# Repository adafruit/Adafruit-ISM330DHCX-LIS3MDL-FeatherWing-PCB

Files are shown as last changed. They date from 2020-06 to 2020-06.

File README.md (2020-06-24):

## Adafruit ISM330DHCX + LIS3MDL FeatherWing - High Precision 9-DoF IMU PCB

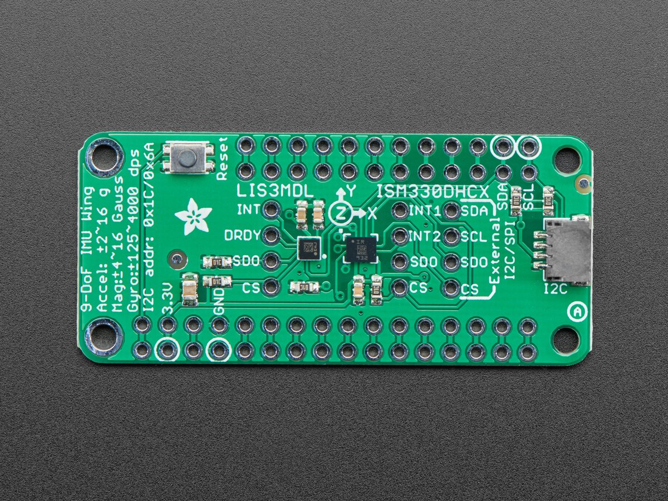
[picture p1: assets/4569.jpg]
<a href="http://www.adafruit.com/products/4569"><br/>
Click here to purchase one from the Adafruit shop</a>

PCB files for the Adafruit ISM330DHCX + LIS3MDL FeatherWing - High Precision 9-DoF IMU.

Format is EagleCAD schematic and board layout
* https://www.adafruit.com/product/4569

### Description

Upgrade any Feather board with precision motion sensing with the ST 9-DoF IMU, an all-in-one sensing 'Wing. It sports two fantastic sensors from ST to provide 9 degrees of full-motion data.

The ST ISM330DHCX is an industrial quality Accelerometer+Gyroscope 6-DOF IMUs (inertial measurement unit). This IMU sensor has 6 degrees of freedom - 3 degrees each of linear acceleration and angular velocity at varying rates within a respectable range. For the accelerometer: ±2/±4/±8/±16 g at 1.6 Hz to 6.7KHz update rate. For the gyroscope: ±125/±250/±500/±1000/±2000/±4000 dps at 12.5 Hz to 6.7 KHz. In particular, this is one of the few gyro's we stock with 4000 dps range, usually they top out at 2000. This sensor has extra calibration and compensation circuits to give it excellent performance in a wide environmental range from -40 to +105°C. Most other IMU sensors don't have industrial temperature ranges or have wide accuracy variation as the temperature changes. The accelerometer and gyroscope also are on the same silicon die, which will keep the 6 measurements synchronized better than when the two sensors are on separate dies.

There are also some nice extras, such as built-in tap detection, activity detection, pedometer/step counter and a programmable finite state machine / machine learning core that can perform some basic gesture recognition.

It also includes a LIS3MDL 3-axis magnetometer that can sense where the strongest magnetic force is coming from, generally used to detect magnetic north. The three triple-axis sensors add up to 9 degrees of freedom, by combining this data you can orient the board. Check out our guide on how to do that!

Both sensors are connected over the shared I2C bus, so you can use it with any and all Feathers! We also break out the interrupt pins and address-selection jumpers in case you want multiple Feathers or have I2C address conflicts. We've got both Arduino (C/C++) and CircuitPython libraries available so you can use it with any Feather board and get data readings in under 5 minutes. Four mounting holes make for a secure connection.

Additionally, since it speaks I2C you can easily connect it up with two wires (plus power and ground!).  We've even included SparkFun qwiic compatible STEMMA QT connectors for the I2C bus so you don't even need to solder! Just wire up to your favorite micro like the STM32F405 Feather with a plug-and-play cable to get 9 DoF data ASAP. You can change the I2C addresses on the back using the solder jumpers, to have two of these sensor boards on one bus.

We also wrote libraries to help you get these sensors integrated with your Arduino/C++. This library covers the accel/gyro and this library is for the magnetometer.

Check out the learning guide here for more information like schematics, wiring diagrams and code libraries.

### License

Adafruit invests time and resources providing this open source design, please support Adafruit and open-source hardware by purchasing products from [Adafruit](https://www.adafruit.com)!

Designed by Limor Fried/Ladyada for Adafruit Industries.

Creative Commons Attribution/Share-Alike, all text above must be included in any redistribution.
See license.txt for additional details.

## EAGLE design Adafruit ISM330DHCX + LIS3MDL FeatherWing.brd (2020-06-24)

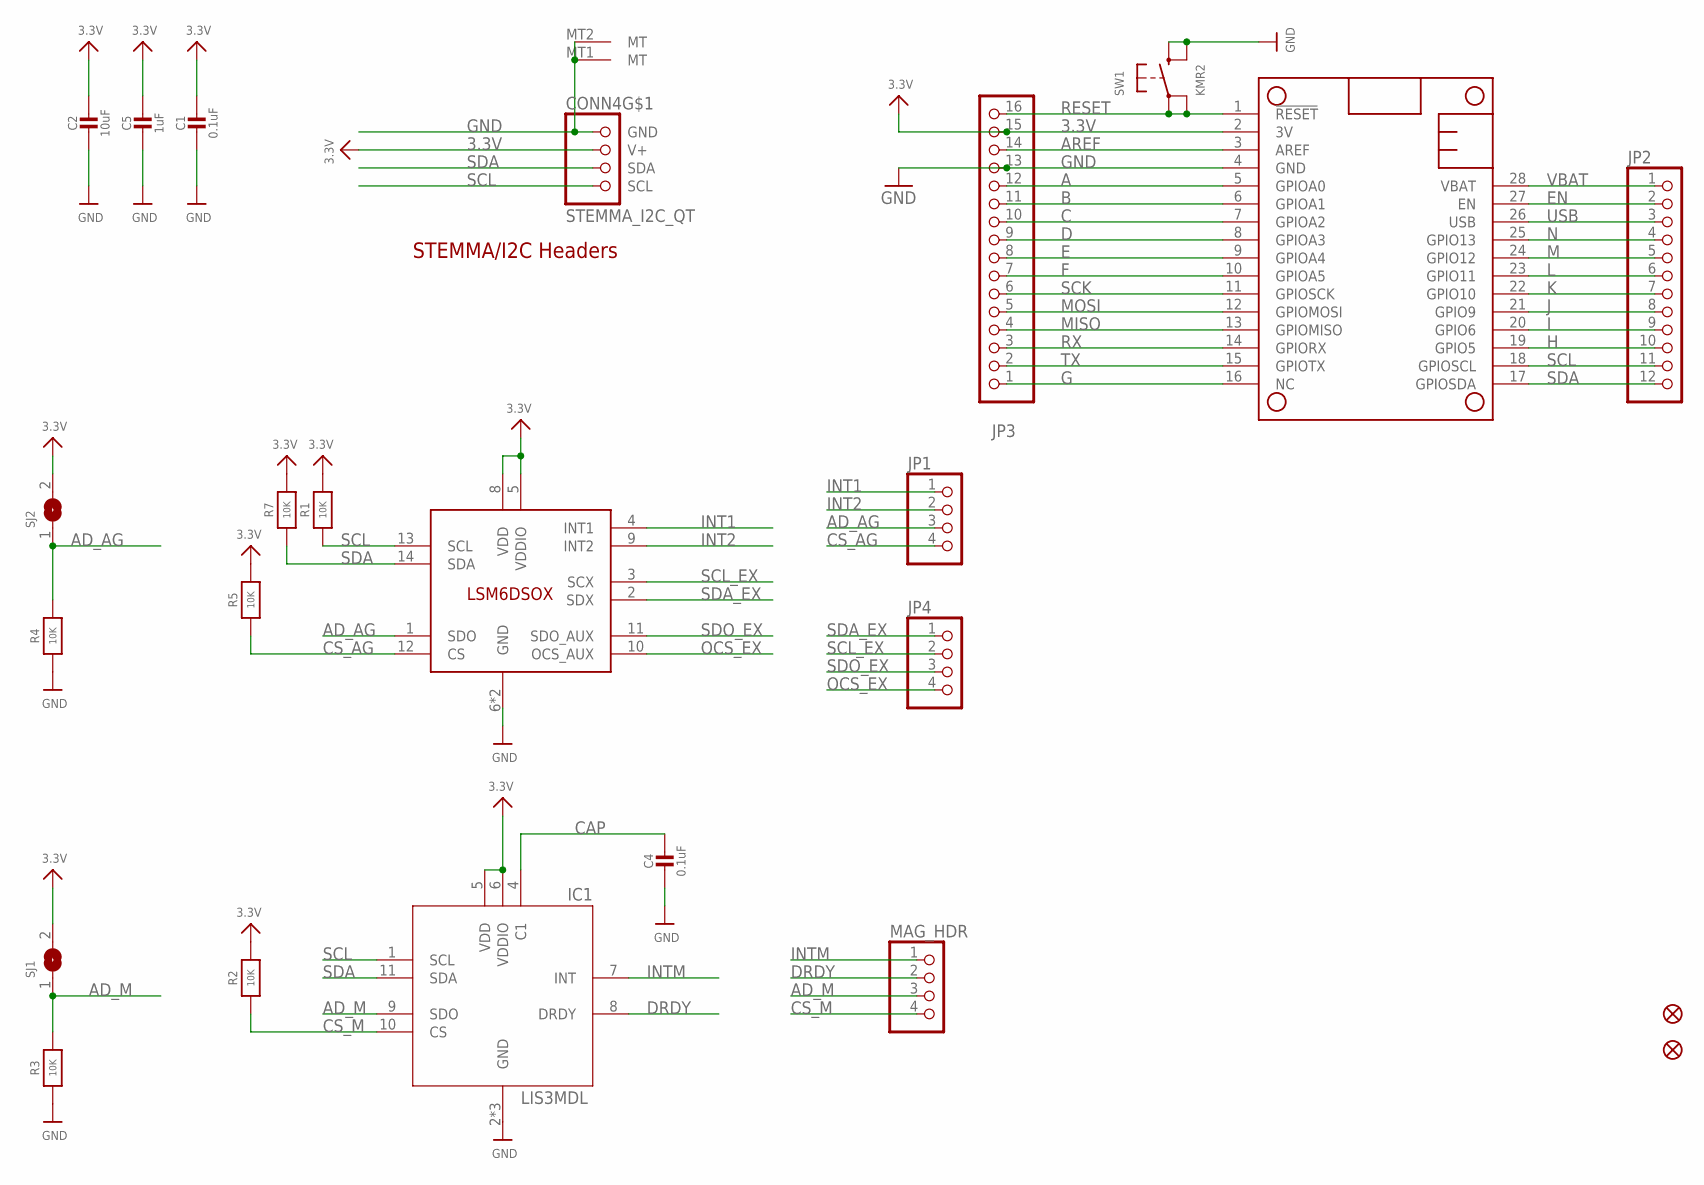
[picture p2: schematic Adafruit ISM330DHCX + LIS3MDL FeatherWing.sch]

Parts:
C1, C4: 0.1uF; 0603-NO
C2: 10uF; 0805-NO
C5: 1uF; 0603-NO
CONN4: STEMMA_I2C_QT; JST_SH4
FID1, FID2: FIDUCIAL_1MM
IC1: LIS3MDL; LGA12_2X2MM
JP1, JP4: HEADER-1X4ROUND; 1X04_ROUND
JP2: HEADER-1X12; 1X12_ROUND
JP3: HEADER-1X16ROUND; 1X16_ROUND
MAG_HDR: HEADER-1X4ROUND; 1X04_ROUND
MS1: FEATHERWING
R1, R2, R3, R4, R5, R7: 10K; 0603-NO
SJ1, SJ2: SOLDERJUMPER; SOLDERJUMPER_ARROW_NOPASTE
SW1: KMR2; BTN_KMR2_4.6X2.8
U$35: LSM6DSOX; LGA-14L

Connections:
3.3V: C1.1, C2.1, C5.1, CONN4.2 (V+), IC1.5 (VDD), IC1.6 (VDDIO), JP3.15, MS1.2 (3V), R1.2, R2.2, R5.2, R7.2, SJ1.2, SJ2.2, U$35.5 (VDDIO), U$35.8 (VDD)
A: JP3.12, MS1.5 (GPIOA0)
AD_AG: JP1.3, R4.2, SJ2.1, U$35.1 (SDO)
AD_M: IC1.9 (SDO), MAG_HDR.3, R3.2, SJ1.1
AREF: JP3.14, MS1.3 (AREF)
B: JP3.11, MS1.6 (GPIOA1)
C: JP3.10, MS1.7 (GPIOA2)
CAP: C4.1, IC1.4 (C1)
CS_AG: JP1.4, R5.1, U$35.12 (CS)
CS_M: IC1.10 (CS), MAG_HDR.4, R2.1
D: JP3.9, MS1.8 (GPIOA3)
DRDY: IC1.8 (DRDY), MAG_HDR.2
E: JP3.8, MS1.9 (GPIOA4)
EN: JP2.2, MS1.27 (EN)
F: JP3.7, MS1.10 (GPIOA5)
G: JP3.1, MS1.16 (NC)
GND: C1.2, C2.2, C4.2, C5.2, CONN4.1 (GND), CONN4.MT1 (MT), CONN4.MT2 (MT), IC1.2 (GND), IC1.3 (GND), IC1.12 (GND), JP3.13, MS1.4 (GND), R3.1, R4.1, SW1.B (S), SW1.B' (S1), U$35.6 (GND), U$35.7 (GND)
H: JP2.10, MS1.19 (GPIO5)
I: JP2.9, MS1.20 (GPIO6)
INT1: JP1.1, U$35.4 (INT1)
INT2: JP1.2, U$35.9 (INT2)
INTM: IC1.7 (INT), MAG_HDR.1
J: JP2.8, MS1.21 (GPIO9)
K: JP2.7, MS1.22 (GPIO10)
L: JP2.6, MS1.23 (GPIO11)
M: JP2.5, MS1.24 (GPIO12)
MISO: JP3.4, MS1.13 (GPIOMISO)
MOSI: JP3.5, MS1.12 (GPIOMOSI)
N: JP2.4, MS1.25 (GPIO13)
OCS_EX: JP4.4, U$35.10 (OCS_AUX)
RESET: JP3.16, MS1.1 (!RESET), SW1.A, SW1.A' (P1)
RX: JP3.3, MS1.14 (GPIORX)
SCK: JP3.6, MS1.11 (GPIOSCK)
SCL: CONN4.4 (SCL), IC1.1 (SCL), JP2.11, MS1.18 (GPIOSCL), R1.1, U$35.13 (SCL)
SCL_EX: JP4.2, U$35.3 (SCX)
SDA: CONN4.3 (SDA), IC1.11 (SDA), JP2.12, MS1.17 (GPIOSDA), R7.1, U$35.14 (SDA)
SDA_EX: JP4.1, U$35.2 (SDX)
SDO_EX: JP4.3, U$35.11 (SDO_AUX)
TX: JP3.2, MS1.15 (GPIOTX)
USB: JP2.3, MS1.26 (USB)
VBAT: JP2.1, MS1.28 (VBAT)

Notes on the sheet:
STEMMA/I2C Headers

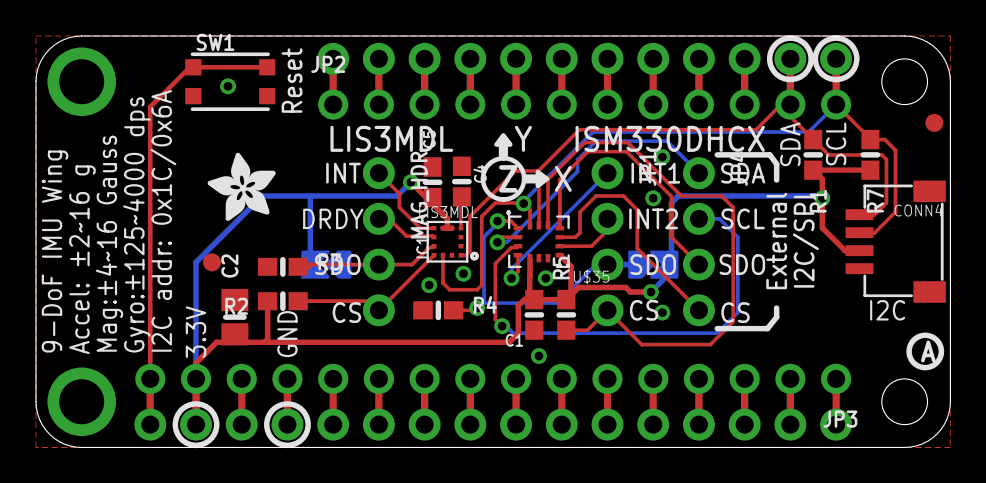
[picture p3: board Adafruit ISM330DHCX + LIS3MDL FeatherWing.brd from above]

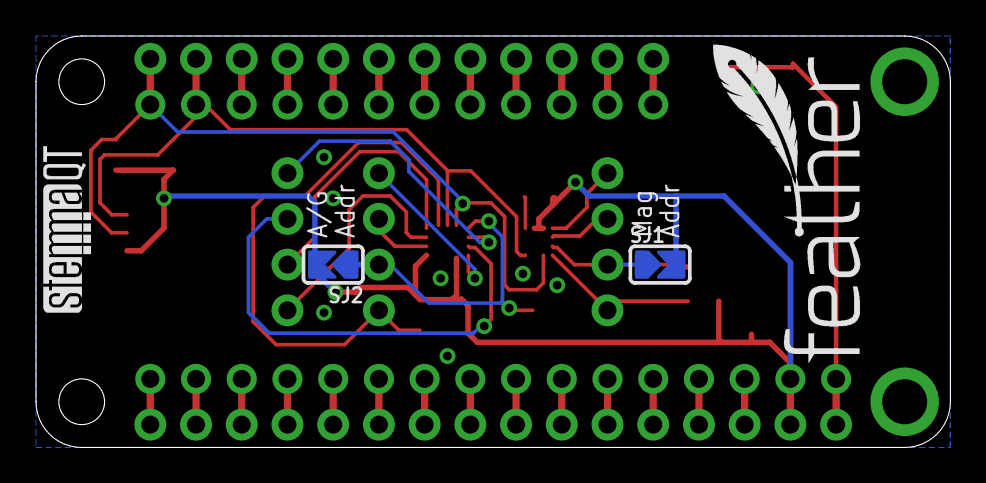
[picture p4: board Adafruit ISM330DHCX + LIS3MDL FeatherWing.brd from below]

Board: 2 copper layers, 50.8 x 22.9 mm, 28 parts (4 on the bottom side), 41 nets.

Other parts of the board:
U$13: FEATHERLOGO_MED
U$31: STEMMAQT
U$50: ADAFRUIT_3.5MM
U$51: PCBFEAT-REV-040

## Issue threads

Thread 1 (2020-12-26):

Silkscreen mislabeled I2C pins

adamgarbo, 2020-12-26:
Hi folks,

A quick note that the SDA and SCL silkscreen labels are incorrectly swapped on this FeatherWing board.

Reported here: https://forums.adafruit.com/viewtopic.php?f=57&t=173318

Cheers,
Adam

ladyada, 2020-12-26:
woops will fix on re-order!

Closed 2020-12-26.

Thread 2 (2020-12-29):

High current consumption during power-down

adamgarbo, 2020-12-29:
Hi folks,

There appears to be an issue with this FeatherWing having a high current consumption when in power-down mode. I'm currently measuring 0.82 mA using a Fluke 287 meter when both the LIS3MDL and ISM330DHCX are manually powered-down.

Related forum post (with code) here: https://forums.adafruit.com/viewtopic.php?f=57&t=173364

When I pull just the LIS3MDL's AD_M to GND, bypassing the 10 kΩ resistor, the power draw drops to ~136 uA. Are the I2C address pins supposed to draw several hundred microamps?

The LIS3MDL and ISM330DHCX are rated as having quiescent draws of 1 µA and 3 µA, respectively, when in power-down mode. It'd be great to see the power efficiency of this board get closer to these figures. Could possible solutions include placing the I2C address resistors on the other side of the jumper and/or using a higher value resistor?

Cheers,
Adam

ladyada, 2020-12-30:
hi yeah that sounds odd but we dont have any insight to the internals
we can revise a future run to add another jumper...it may be a bit because we ordered PCBs recently and we dont sell a ton. for now we recommend soldering some wire to make a jumper!

adamgarbo, 2021-01-04:
Thanks @ladyada!

I don't think the issue is related to the sensors themselves, but more the resistance values of the pull-down/up resistors. If I have time, I'll try to isolate where all the remaining draw is coming from and report back. No rush!

Cheers,
Adam

Closed 2020-12-30.

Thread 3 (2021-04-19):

Provide pdf of the board schematic

jerabaul29, 2021-04-19:
Could you provide a pdf dump of the schematics? That makes it much easier to look at 'on the go' and or when Eagle is not installed / available :) .

ladyada, 2021-04-19:
https://learn.adafruit.com/st-9-dof-combo/downloads

Closed 2021-04-19.

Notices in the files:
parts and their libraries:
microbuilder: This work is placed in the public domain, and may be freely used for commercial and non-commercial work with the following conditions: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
